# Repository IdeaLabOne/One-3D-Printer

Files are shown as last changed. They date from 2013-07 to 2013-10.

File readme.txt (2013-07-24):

Czesci do drukarki sa udostepnione w calosci, 1 sierpnia pojawi sie instrukcja montazu wraz z Lista potrzebnych czesci.
Jesli poprawisz jakies elementy z checia je udostepniê. Projekt jest w wersji 0.9 beta, prototyp dziala mam swiadomosc ze wiele rzeczy mozna by bylo zrobic lepiej i tak tez pewnie zostana poprawione wiec zagladaj tu czasem byc moze jakies czesci zostaly poprawione.

Parts of the printer are available August 1 will be installation instructions along with a list of necessary parts.
If you upgrade any components share them.The project is in version 0.9 beta prototype work I am aware of the many things one could do better, and so also likely will be revised so check here sometimes there may be a part of have been corrected.

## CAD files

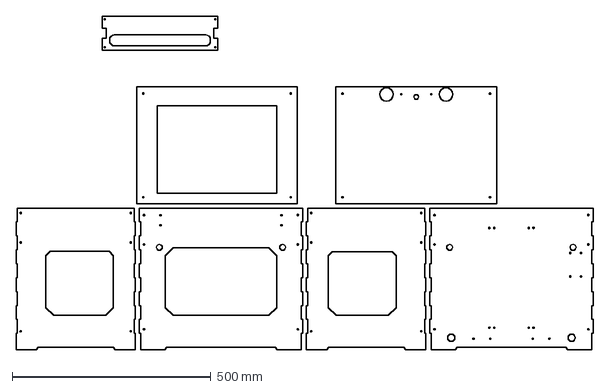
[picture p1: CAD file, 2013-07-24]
dibond frame/dibond 3mm frame.dxf
1450.0 x 837.9 mm

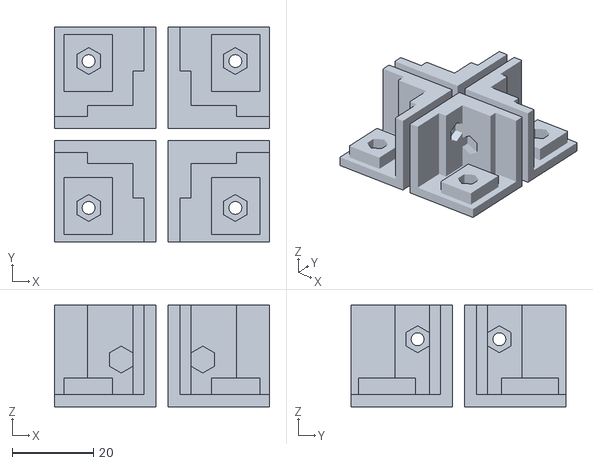
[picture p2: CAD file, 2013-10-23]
Printed Parts/corners/bottom.stl
52.9 x 52.9 x 25.0

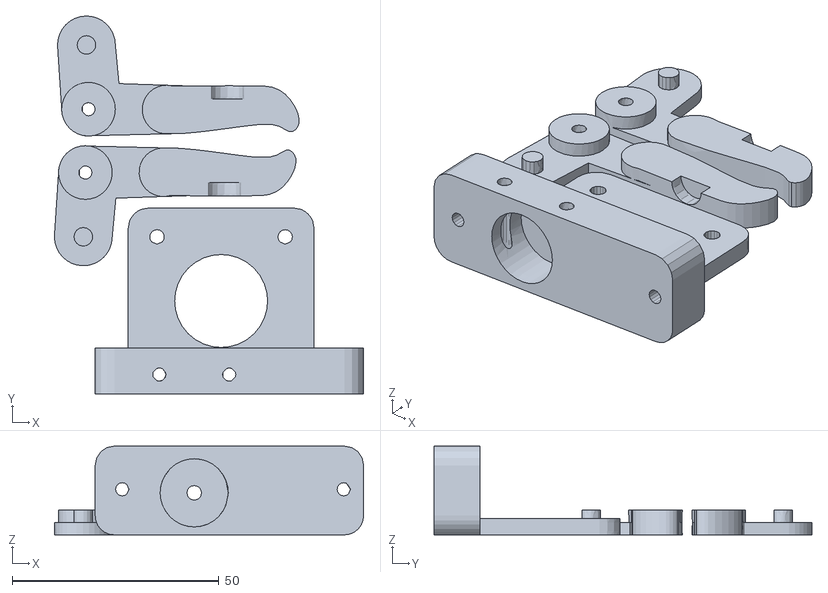
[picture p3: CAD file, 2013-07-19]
Printed Parts/extruder/extruder.stl
74.8 x 91.4 x 21.5

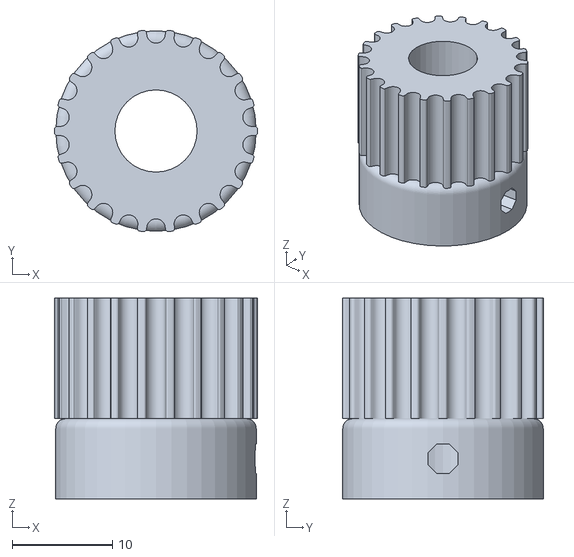
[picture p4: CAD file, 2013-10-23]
Printed Parts/gears/Pulley_hdt 8mm 22 zebyh.stl
20.2 x 20.1 x 20.0

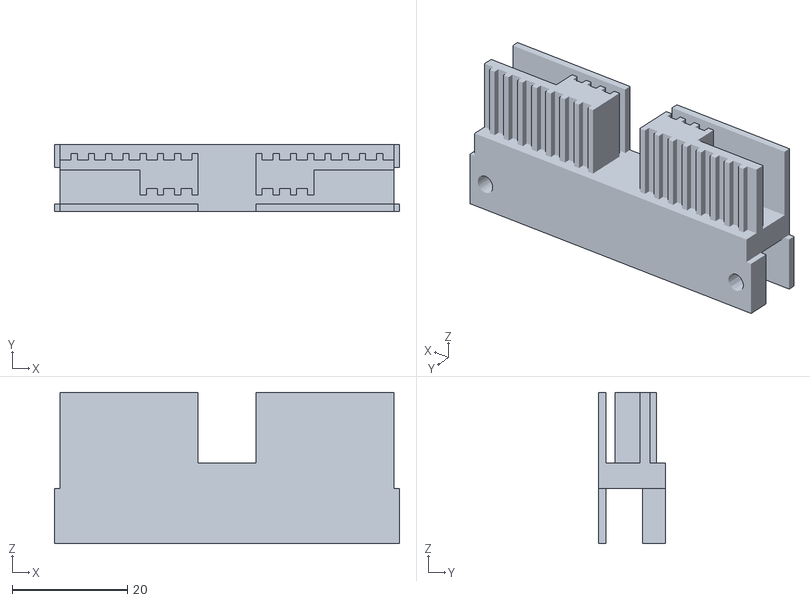
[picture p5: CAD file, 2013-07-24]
Printed Parts/x axis/x tensioner.stl
60.0 x 11.7 x 26.3

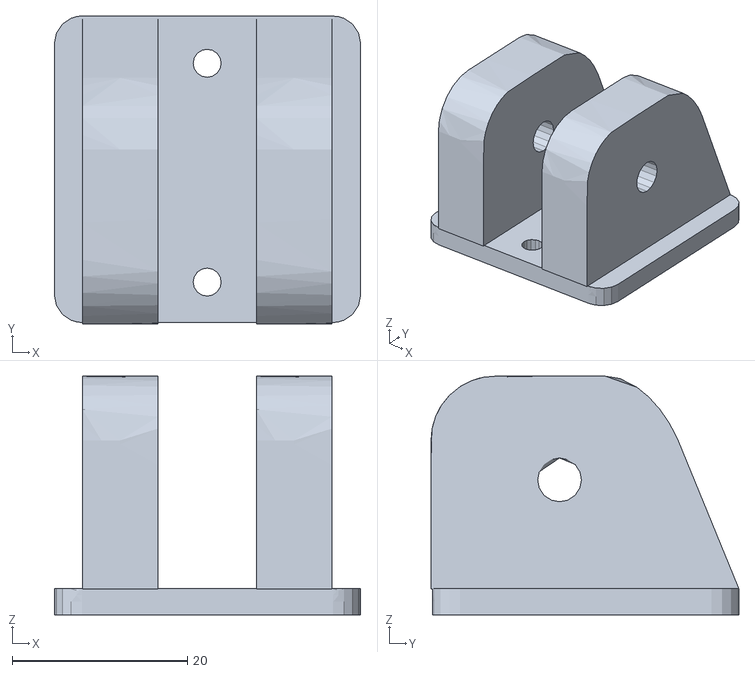
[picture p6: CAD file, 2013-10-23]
Printed Parts/y axis/y bearing 2x.stl
35.0 x 35.2 x 27.3

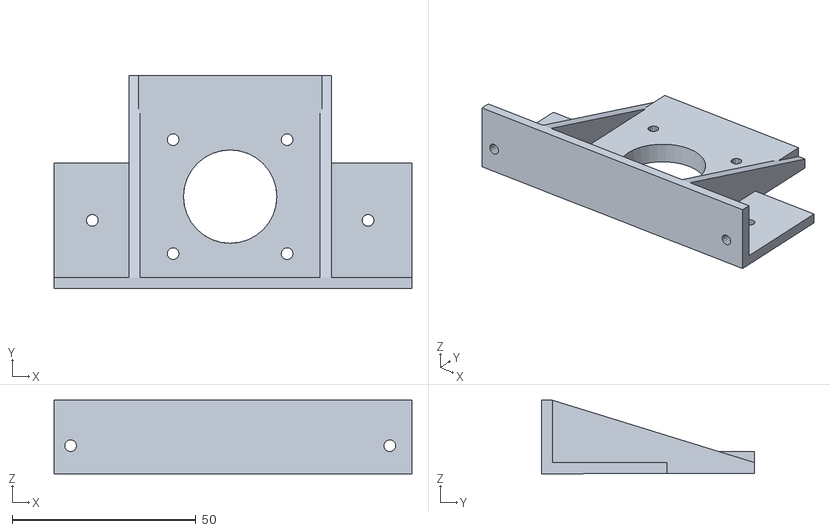
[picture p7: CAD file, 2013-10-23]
Printed Parts/z axis/z motor.stl
97.4 x 58.1 x 20.0

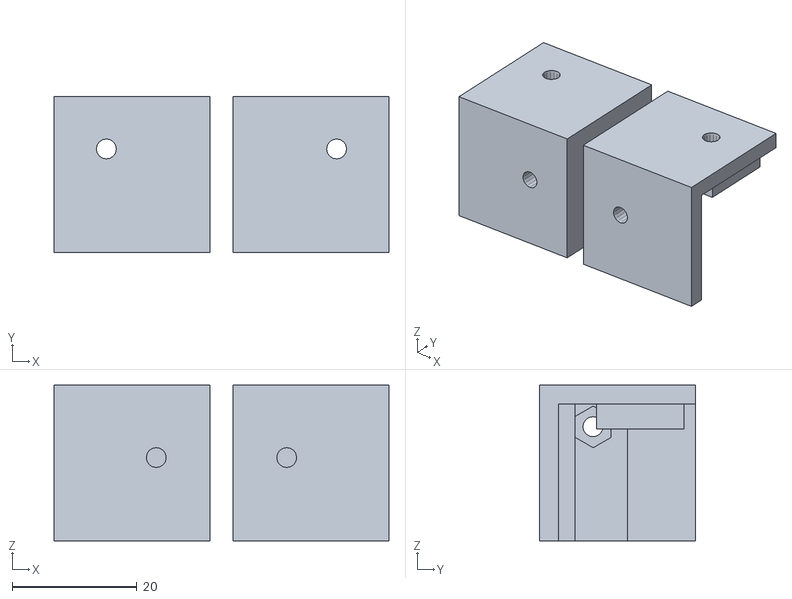
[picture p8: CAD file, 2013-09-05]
Printed Parts/corners/block top front.stl
53.7 x 25.0 x 25.0

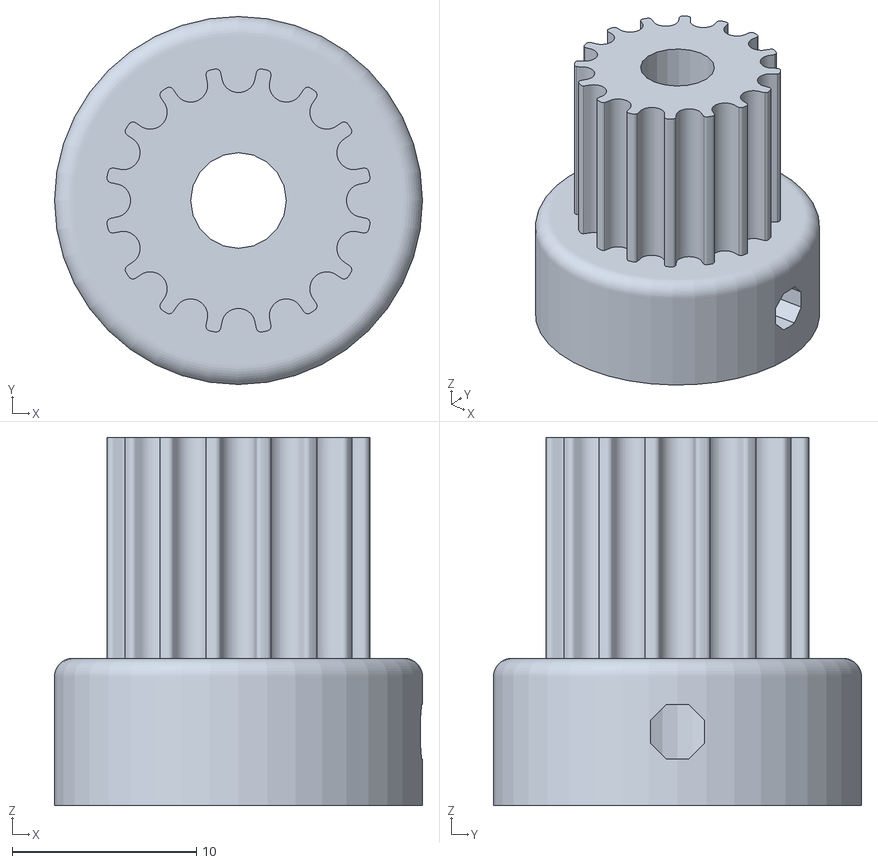
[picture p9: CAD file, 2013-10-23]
Printed Parts/gears/Pulley_hdt16 sil-tooth.stl
20.0 x 20.0 x 20.0

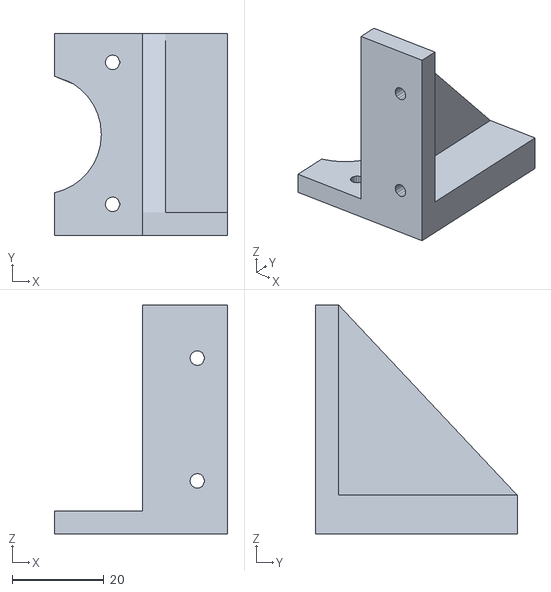
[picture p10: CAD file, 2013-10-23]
Printed Parts/y axis/y motor.stl
37.8 x 44.0 x 50.0

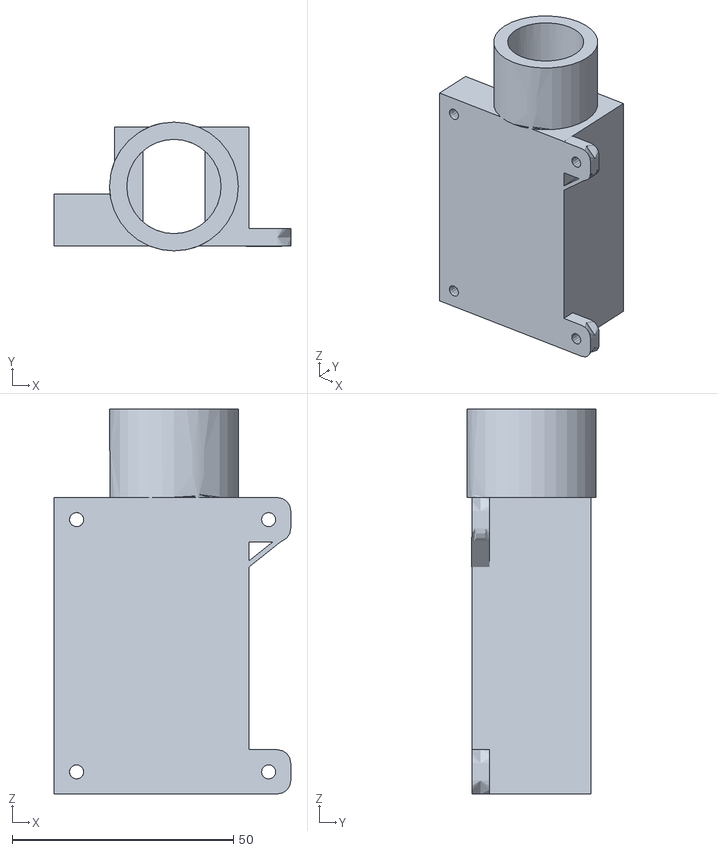
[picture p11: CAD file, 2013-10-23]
Printed Parts/z axis/bearing holder.stl
53.5 x 29.1 x 87.0

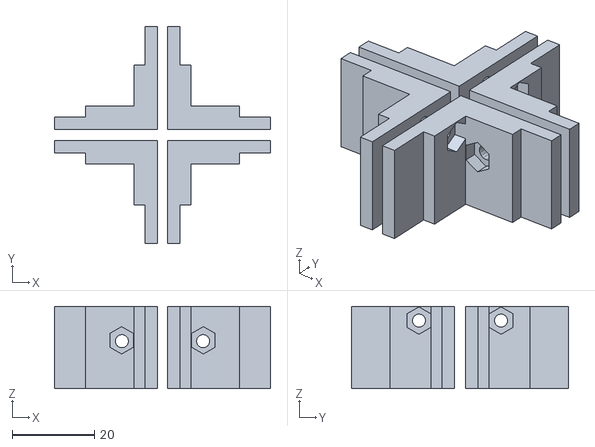
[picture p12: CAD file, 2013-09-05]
Printed Parts/corners/block middle.stl
52.5 x 52.7 x 20.0

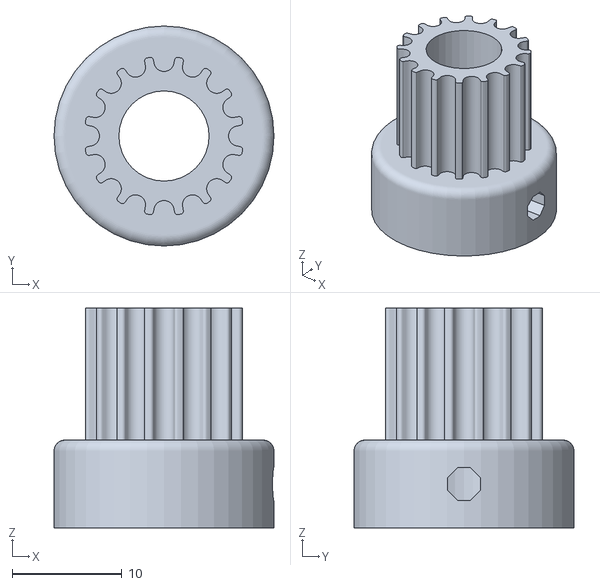
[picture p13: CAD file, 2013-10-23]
Printed Parts/gears/Pulley_HTD-walek-16tooth.stl
20.0 x 20.0 x 20.0

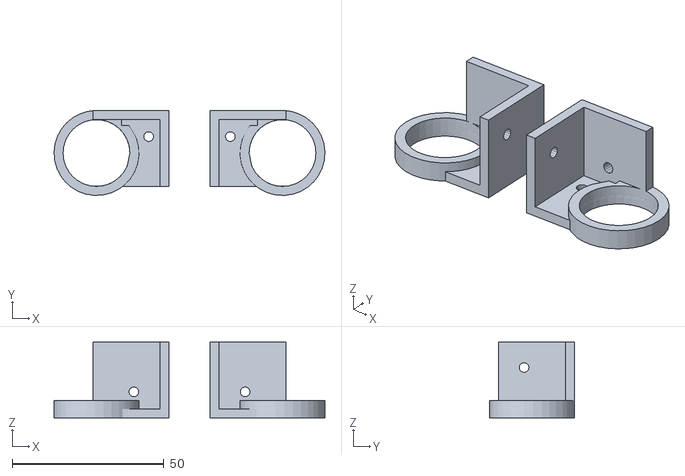
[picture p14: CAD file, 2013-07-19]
Printed Parts/y axis/y drive rod bracket.stl
89.3 x 28.0 x 25.0

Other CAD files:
Printed Parts/z axis/z bottom 2x.stl
Printed Parts/y axis/y smooth rod caps.stl
Printed Parts/z axis/top Z.stl
Printed Parts/z axis/table mount.stl
Printed Parts/z axis/z middle trapez.stl

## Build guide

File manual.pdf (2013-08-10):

# Idea Lab One

## instrukcja montażu build manual

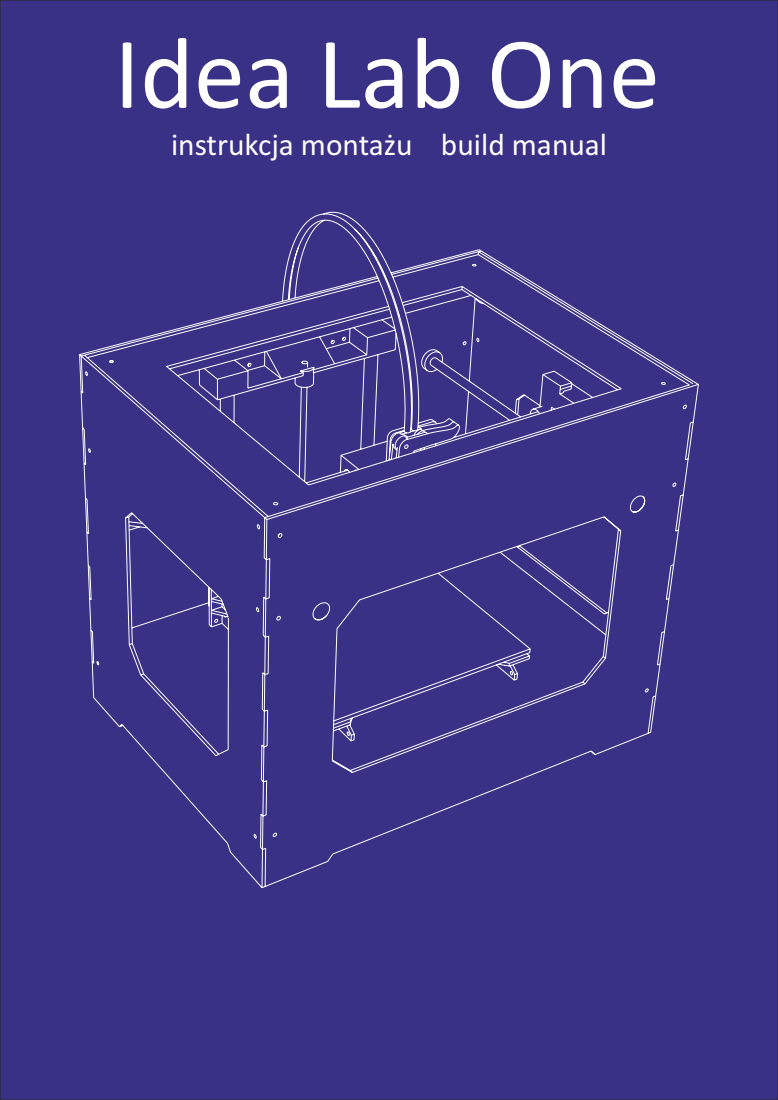
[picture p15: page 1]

# Bill of materials

-Cnc cued dibond frame
-50x M3x8mm and 50 M3 nuts -8mm smooth roods:
- 1 x 404mm
- 2 x 294mm
- 2 x 284mm
- 2 x 12mm smooth roods 255mm
- set of printed plasc parts
- reprap electronics minimum 4 axis with all neded connectors
- 8 x LM8UU bearings
- 4 x LM12UU bearings
- table aluminium frame
- 24v power supply
- cables 4 wire and 2 wire
- 4 nema17 motors
- hotend jhead compable
- spring 10mm outer diameter and 6mm outer diameter
- mk7 filament pulley
- 4 heang resisitors
- 200mm x150mm glass
- 3x mechanical endstop switch
- 1 x 100k thermistor
- HDT 3M ming belts 2 meters
- HDT 3M belt enclosed 282mm
- 2x m8 nut and 220mm of threaded rod m8

## Before assembly check whole manual maybe You will find better way or better step organisation for assembly

## Step 1

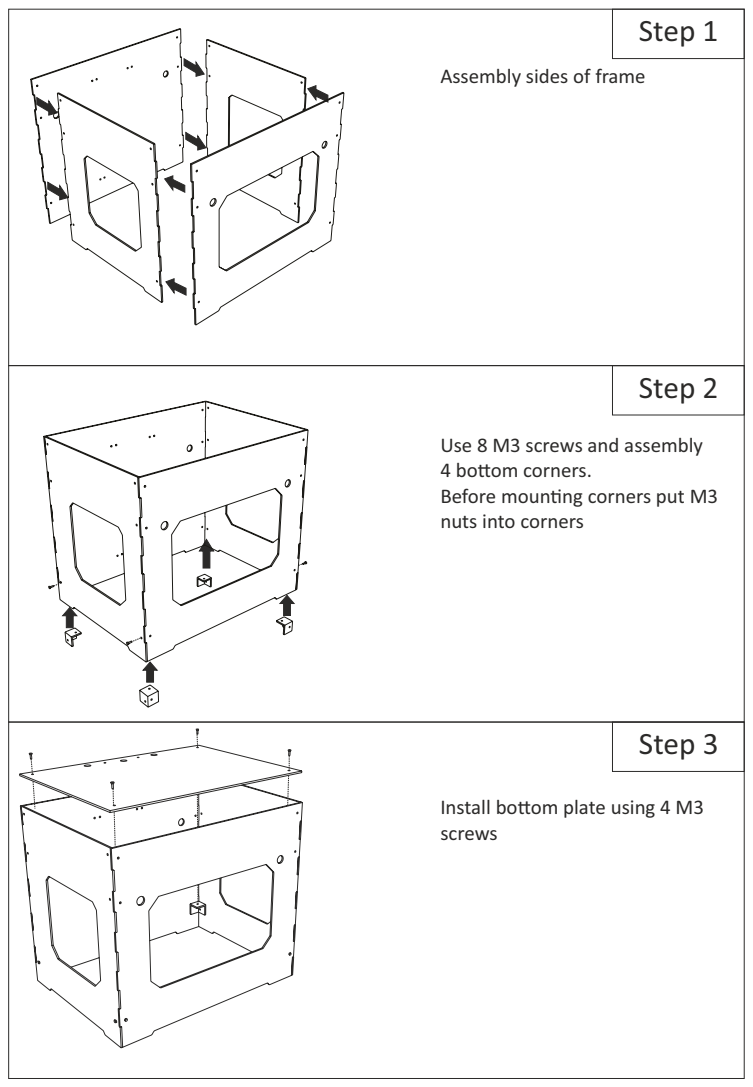
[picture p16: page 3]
Step 2; Step 3

Assembly sides of frame

Use 8 M3 screws and assembly
4 boom corners.
Before mounng corners put M3
nuts into corners

Install boom plate using 4 M3
screws

## Step 4

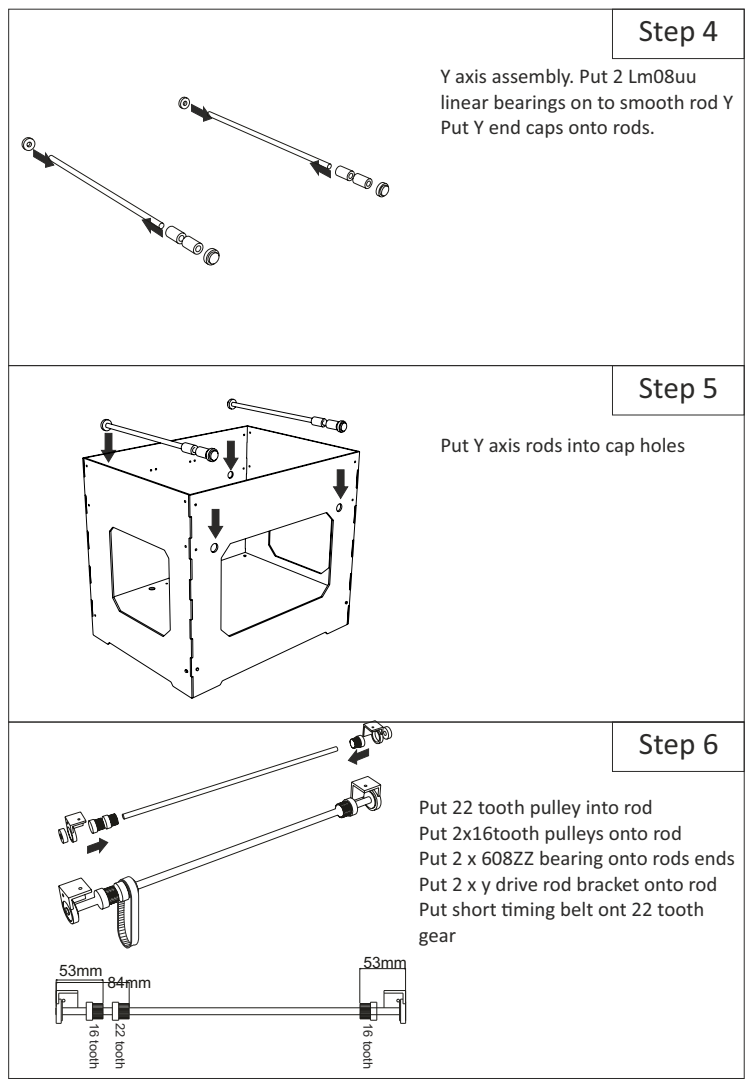
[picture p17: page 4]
Step 5; Step 6; 16 tooth; 22 tooth

Y axis assembly. Put 2 Lm08uu
linear bearings on to smooth rod Y
Put Y end caps onto rods.

Put Y axis rods into cap holes

Put 22 tooth pulley into rod
Put 2x16tooth pulleys onto rod
Put 2 x 608ZZ bearing onto rods ends
Put 2 x y drive rod bracket onto rod
Put short ming belt ont 22 tooth
gear

## Step 7

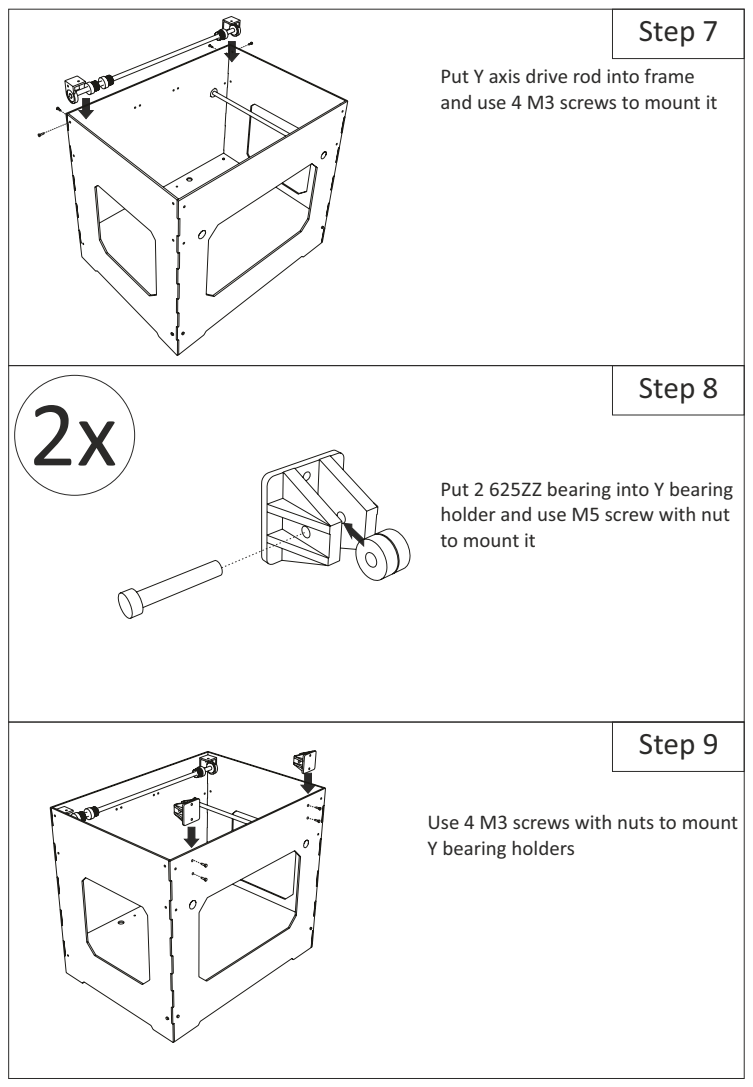
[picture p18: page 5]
Step 8; Step 9

Put Y axis drive rod into frame
and use 4 M3 screws to mount it

Put 2 625ZZ bearing into Y bearing
holder and use M5 screw with nut
to mount it

Use 4 M3 screws with nuts to mount
Y bearing holders

## Step 10

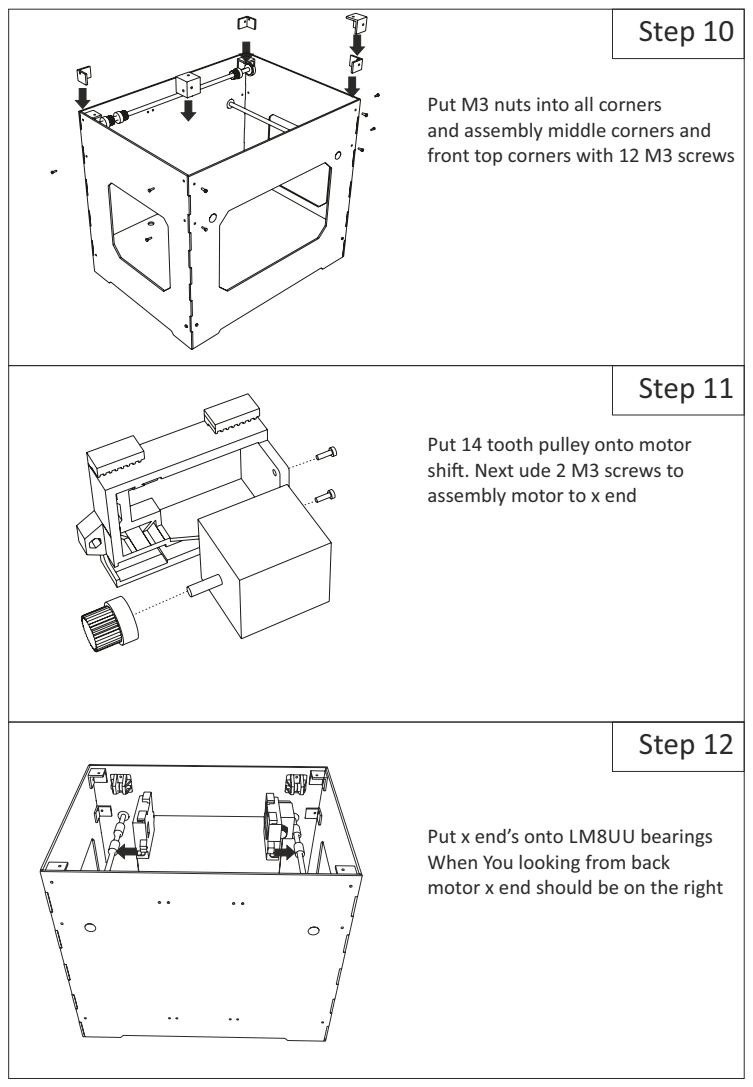
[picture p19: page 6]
Step 11; Step 12

Put M3 nuts into all corners
and assembly middle corners and
front top corners with 12 M3 screws

Put 14 tooth pulley onto motor
shi. Next ude 2 M3 screws to
assembly motor to x end

Put x end’s onto LM8UU bearings
When You looking from back
motor x end should be on the right

## Step 13

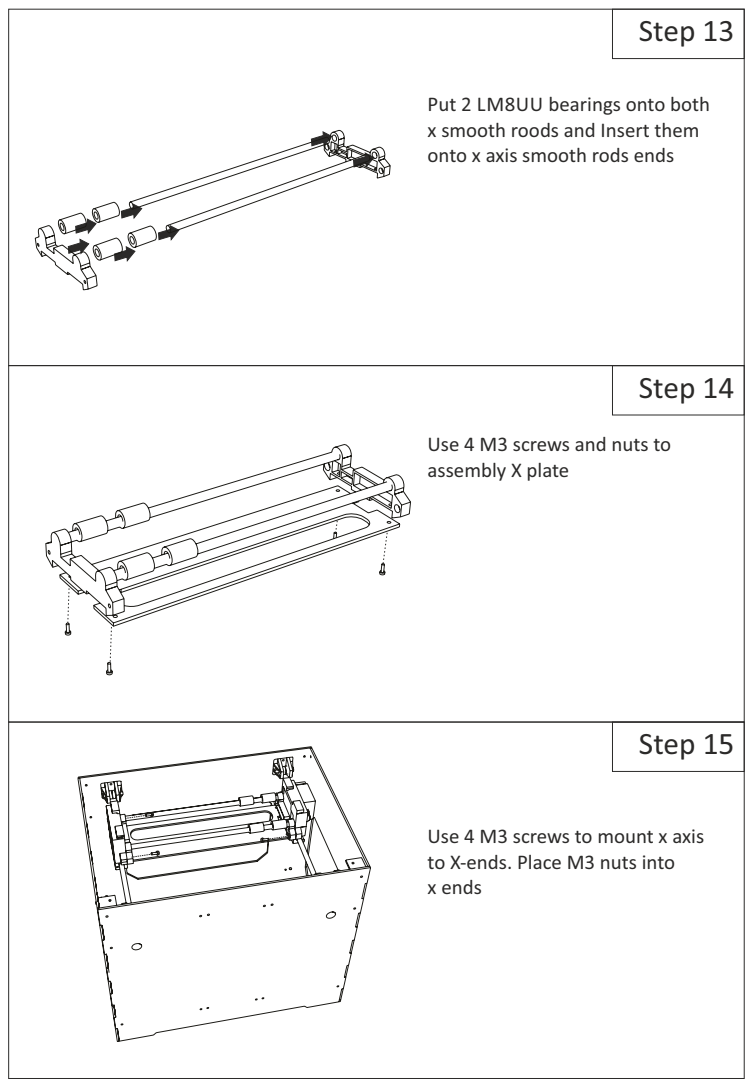
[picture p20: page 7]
Step 14; Step 15

Put 2 LM8UU bearings onto both
x smooth roods and Insert them
onto x axis smooth rods ends

Use 4 M3 screws and nuts to
assembly X plate

Use 4 M3 screws to mount x axis
to X-ends. Place M3 nuts into
x ends

## Step 16

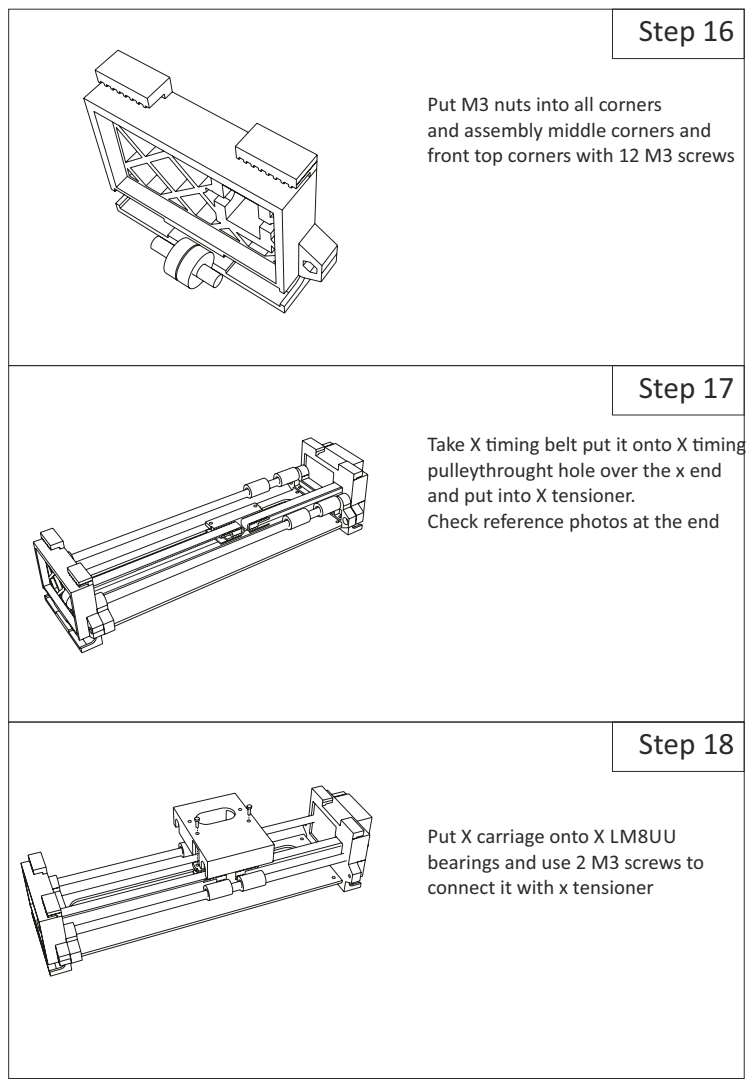
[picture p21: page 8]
Step 17; Step 18

Put M3 nuts into all corners
and assembly middle corners and
front top corners with 12 M3 screws

Take X ming belt put it onto X ming
pulleythrought hole over the x end
and put into X tensioner.
Check reference photos at the end

Put X carriage onto X LM8UU
bearings and use 2 M3 screws to
connect it with x tensioner

## Step 19

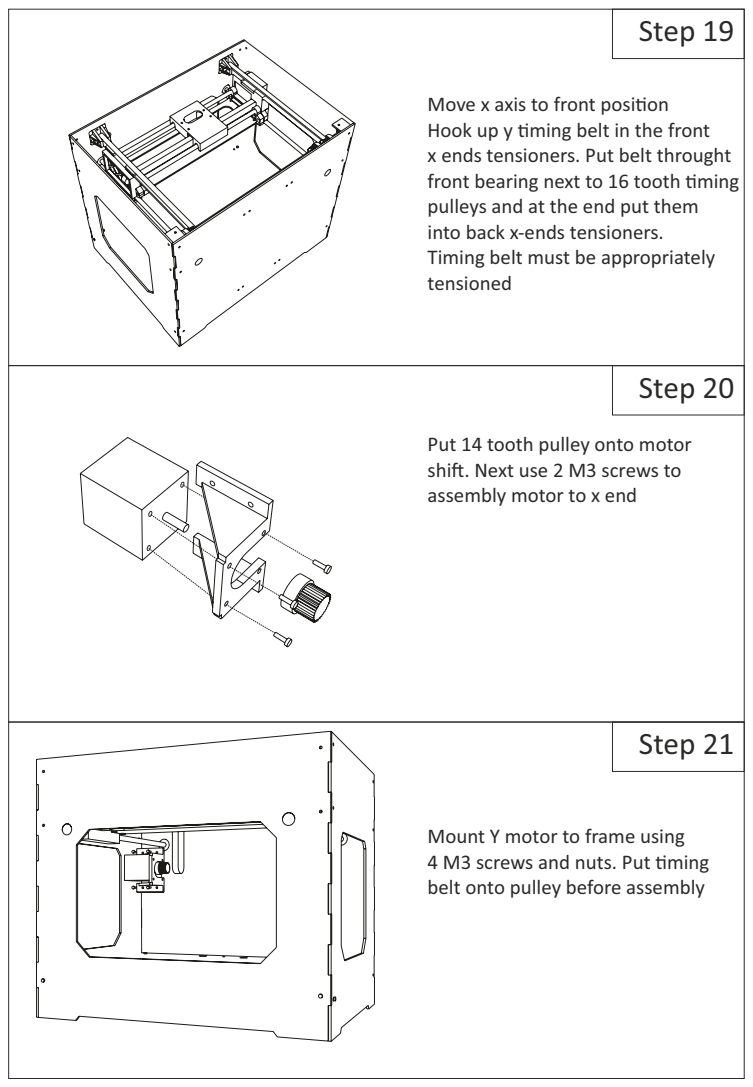
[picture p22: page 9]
Step 20; Step 21

Move x axis to front posion
Hook up y ming belt in the front
x ends tensioners. Put belt throught
front bearing next to 16 tooth ming
pulleys and at the end put them
into back x-ends tensioners.
Timing belt must be appropriately
tensioned

Put 14 tooth pulley onto motor
shi. Next use 2 M3 screws to
assembly motor to x end

Mount Y motor to frame using
4 M3 screws and nuts. Put ming
belt onto pulley before assembly

## Step 22

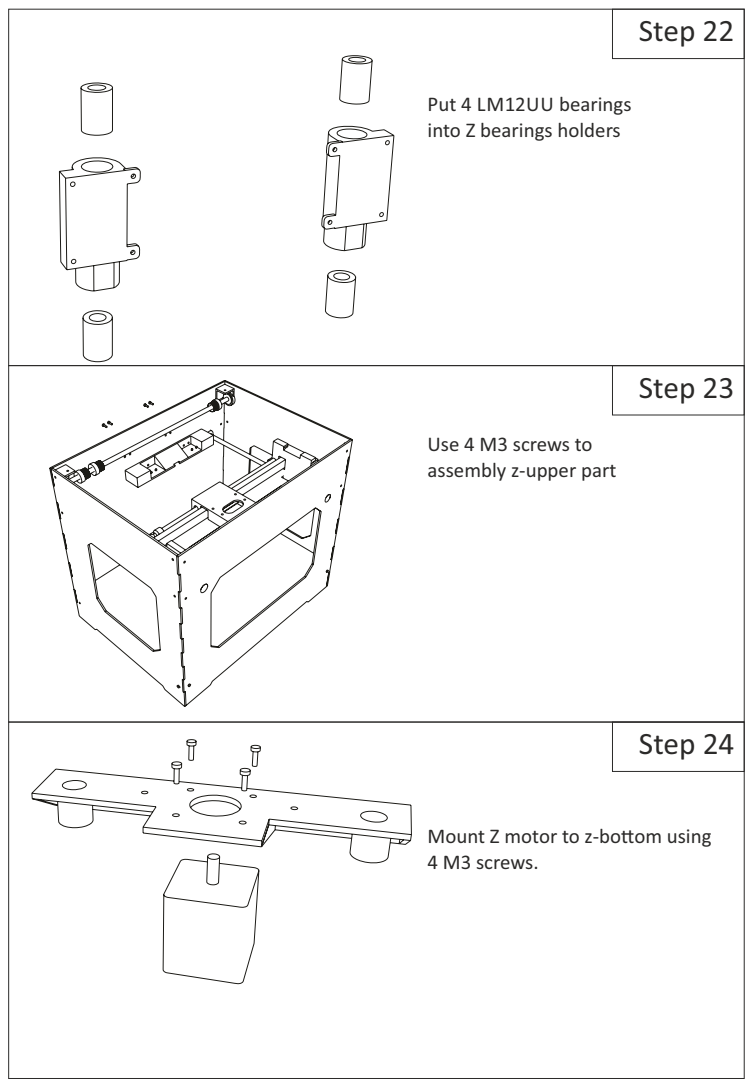
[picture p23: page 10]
Step 23; Step 24

Put 4 LM12UU bearings
into Z bearings holders

Use 4 M3 screws to
assembly z-upper part

Mount Z motor to z-boom using
4 M3 screws.

## Step 25

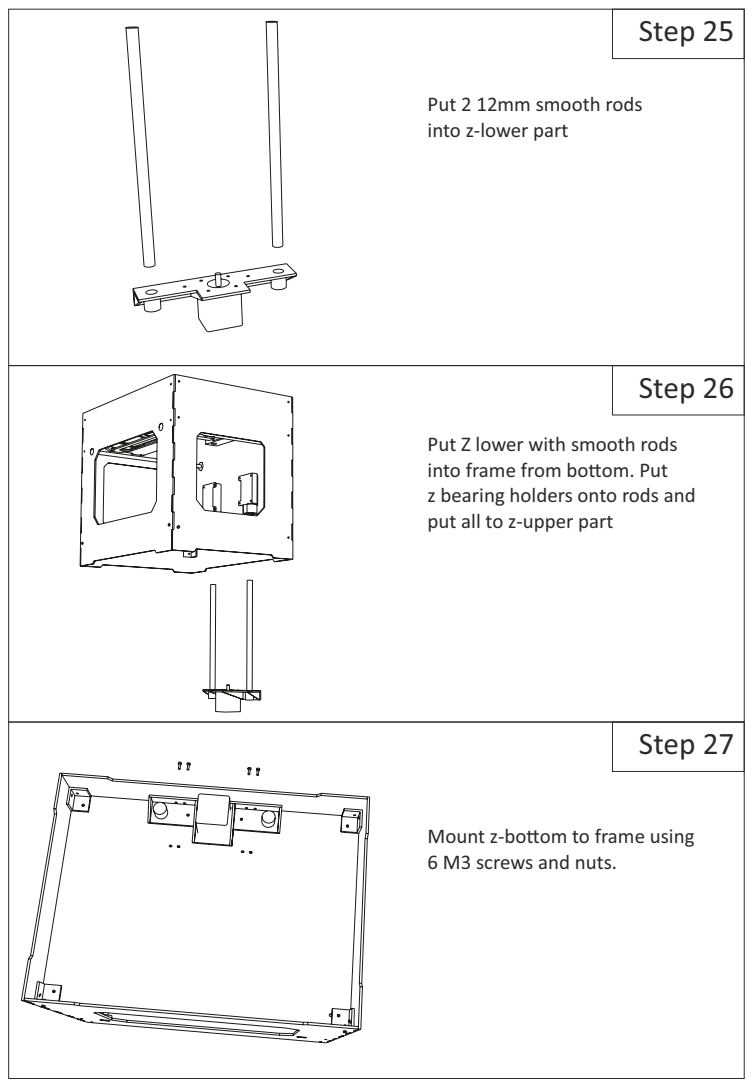
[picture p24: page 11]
Step 26; Step 27

Put 2 12mm smooth rods
into z-lower part

Put Z lower with smooth rods
into frame from boom. Put
z bearing holders onto rods and
put all to z-upper part

Mount z-boom to frame using
6 M3 screws and nuts.

## Step 28

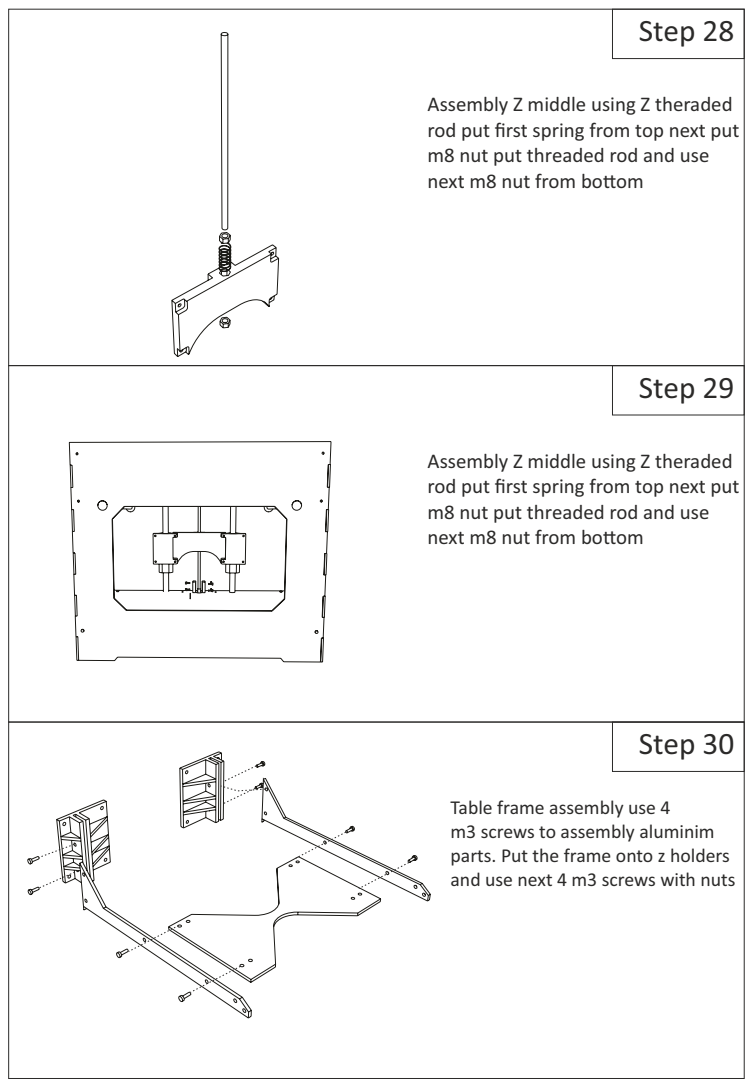
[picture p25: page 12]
Step 29; Step 30

Assembly Z middle using Z theraded
rod put first spring from top next put
m8 nut put threaded rod and use
next m8 nut from boom

Table frame assembly use 4
m3 screws to assembly aluminim
parts. Put the frame onto z holders
and use next 4 m3 screws with nuts

## Step 31

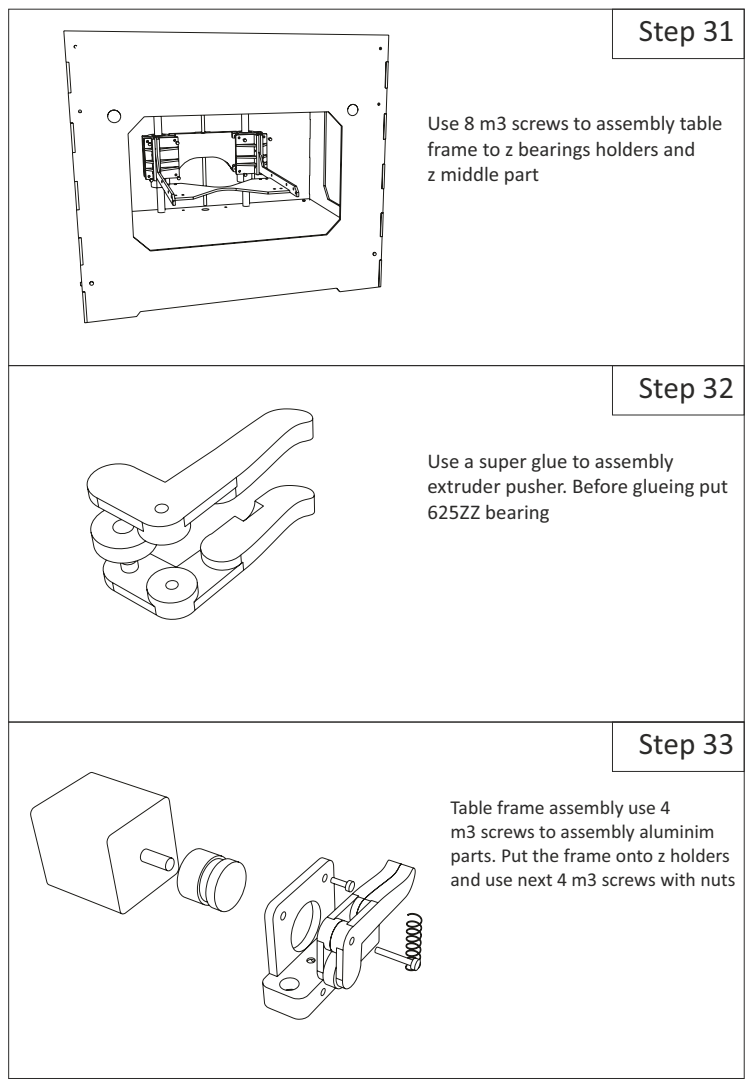
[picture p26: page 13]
Step 32; Step 33

Use 8 m3 screws to assembly table
frame to z bearings holders and
z middle part

Use a super glue to assembly
extruder pusher. Before glueing put
625ZZ bearing

Table frame assembly use 4
m3 screws to assembly aluminim
parts. Put the frame onto z holders
and use next 4 m3 screws with nuts

## Step 34

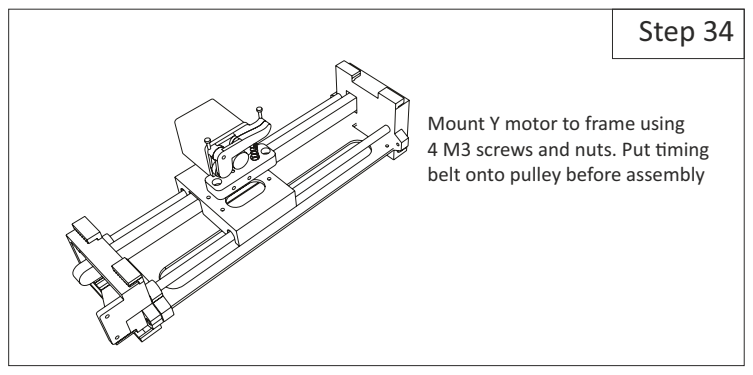
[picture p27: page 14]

Mount Y motor to frame using
4 M3 screws and nuts. Put ming
belt onto pulley before assembly

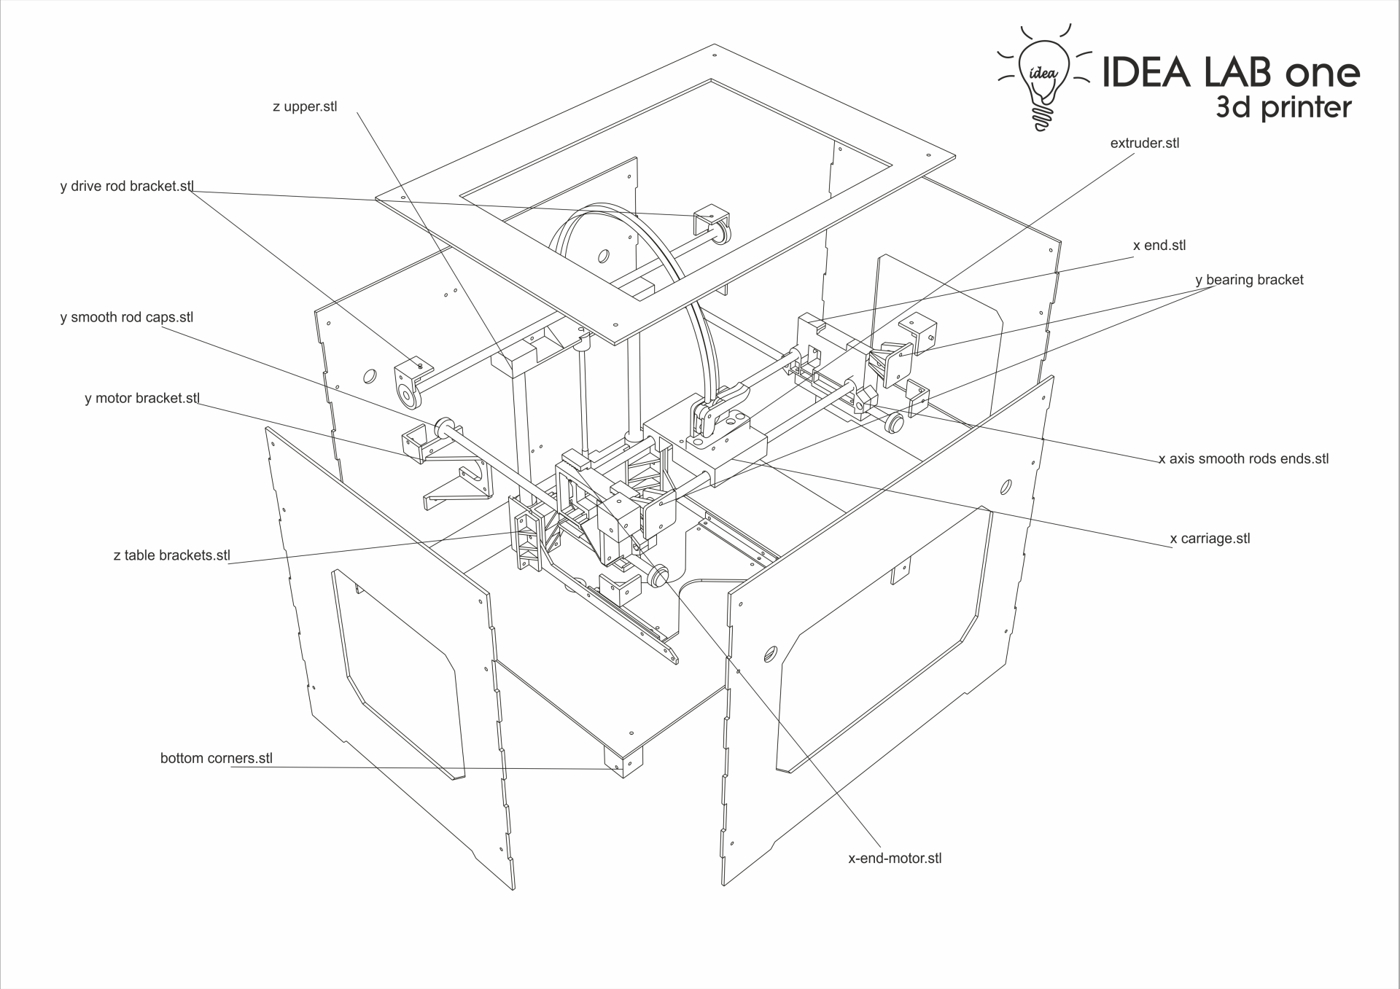
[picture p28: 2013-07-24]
assembly.png

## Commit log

2013-07-19 First Upload
    [extruder.stl, y bearing bracket x 2.stl, y drive rod bracket.stl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]
2013-07-19 3mm dibond frame ver 0.9
    [dibond 3mm frame.dxf]
2013-07-24 Next uploads
    [dibond 3mm frame.dxf, x tensioner.stl]
2013-07-24 Correct holes
    [dibond 3mm frame.dxf]
2013-07-24 Assembly image
2013-07-30 Manual update frame assembly
2013-08-10 Manual update with BOM
